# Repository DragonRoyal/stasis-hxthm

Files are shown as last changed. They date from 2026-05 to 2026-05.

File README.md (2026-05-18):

# 3D Cursor Robotic Arm

A robotic arm controlled by a **barcode-scanned spherical dome** (“3D cursor”). By scanning different barcodes inside the dome with a barcode scanner, the arm moves to different points / presets. That same ability to control a robotic arm in a enclosed 3d space can be used in other applications such as a 3D mouse for cad, or even helping older people with wrist shakiness to autonomously pick and control objects

## Demo
- Video/demo: https://www.youtube.com/watch?v=vmy95ypN5ZI

## What this is
- **3D‑printed structure** (links, brackets, mounts)
- **SG90 micro servo** for a light-duty joint / end-effector motion
- **Larger servo** (MG996R-class) for higher-torque joint motion
- **28BYJ-48 5V stepper motor** for the base axis / positioning
- **Arduino Nano** as the main controller

## Bill of Materials (BOM)

| Category | Item | Qty | Notes |
|---|---:|---:|---|
| 3D Printed | Arm links (upper/lower) | 1 set | Print in PLA/PETG |
| 3D Printed | Servo brackets / mounts | 1 set | For SG90 + MG996R |
| 3D Printed | Stepper mount | 1 | For 28BYJ-48 |
| 3D Printed | Base plate + lid | 1 set | Houses electronics |
| 3D Printed | End-effector / claw parts | 1 set | See CAD folder |
| 3D Printed | Cable guides / strain relief | as needed | Optional but helpful |
| Electronics | Arduino Nano | 1 | Main controller |
| Electronics | SG90 micro servo | 1 | Small joint / gripper |
| Electronics | MG996R servo (or similar) | 1 | Higher torque joint |
| Electronics | 28BYJ-48 5V stepper motor | 1 | Base axis |
| Electronics | Stepper driver board (ULN2003) | 1 | Common driver for 28BYJ-48 |
| Electronics | Power supply breakout boards | 1+ | As used in build |
| Electronics | 9V batteries | 1+ | As used in build |
| Electronics | Jumper wires | 1 set | Male/male + male/female |
| Electronics | Breadboard / perfboard | 0–1 | Optional |
| Hardware | M3 screws + nuts | assorted | Primary fasteners |
| Hardware | Heat-set inserts | optional | Recommended for durability |
| Hardware | Zip ties / Velcro | assorted | Cable management |
| Tools | 3D printer | 1 | — |
| Tools | Soldering iron + solder | 1 | — |
| Tools | Hex drivers / screwdrivers | 1 set | — |

## Pictures

Build photos (preview):

Arm build photo 1

Arm build photo 2

## CAD

CAD Photo

## Electronics

Wiring / electronics photo (preview):

Electronics photo

## Firmware / Control
Hand detection with opencv, it can detect joints and observe open/close positions
Firmware / control notes (preview):

Firmware photo 1

Firmware photo 2

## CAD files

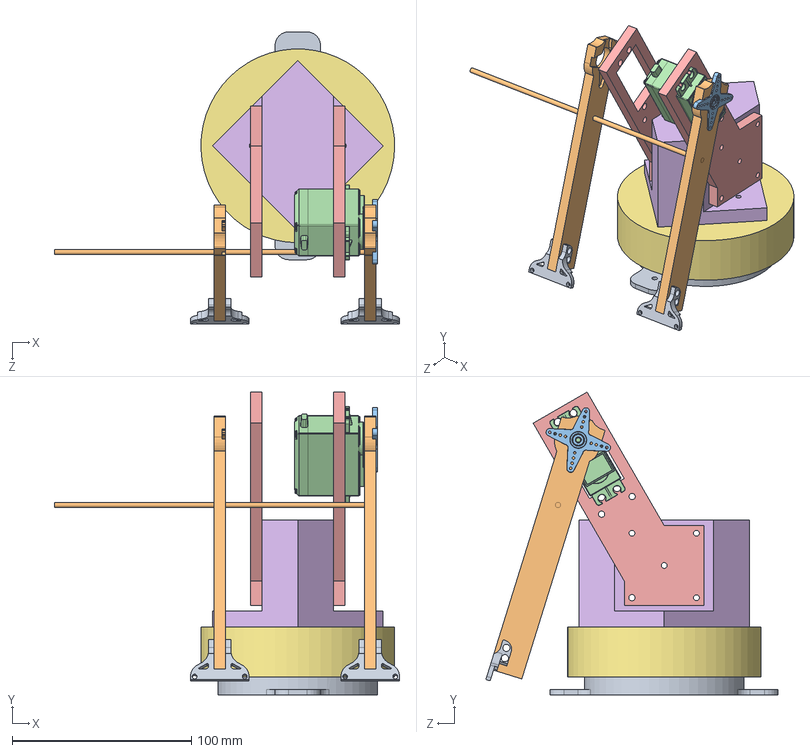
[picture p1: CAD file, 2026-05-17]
cad/Assembly.SLDASM
192.2 x 168.8 x 162.9 mm
Base
Stepper motor 28BYJ-48 5V
BaseLid
ArmGusset
LowerArm x 2
MG996R Motor
4-star horn
armLinkage x 2
adapter x 2

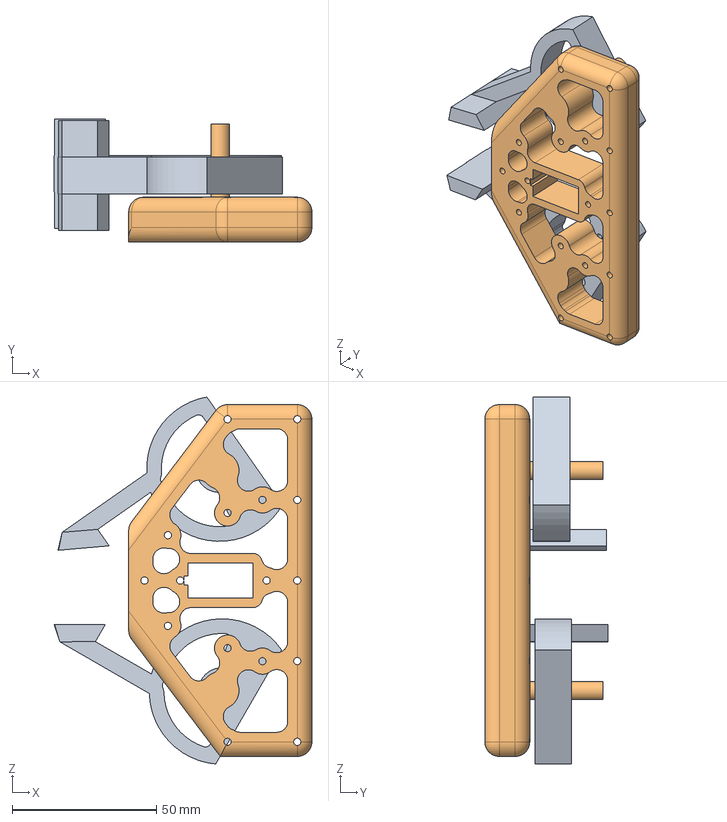
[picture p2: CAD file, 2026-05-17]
cad/STL/FullClaw.step
89.4 x 42.8 x 127.2 mm

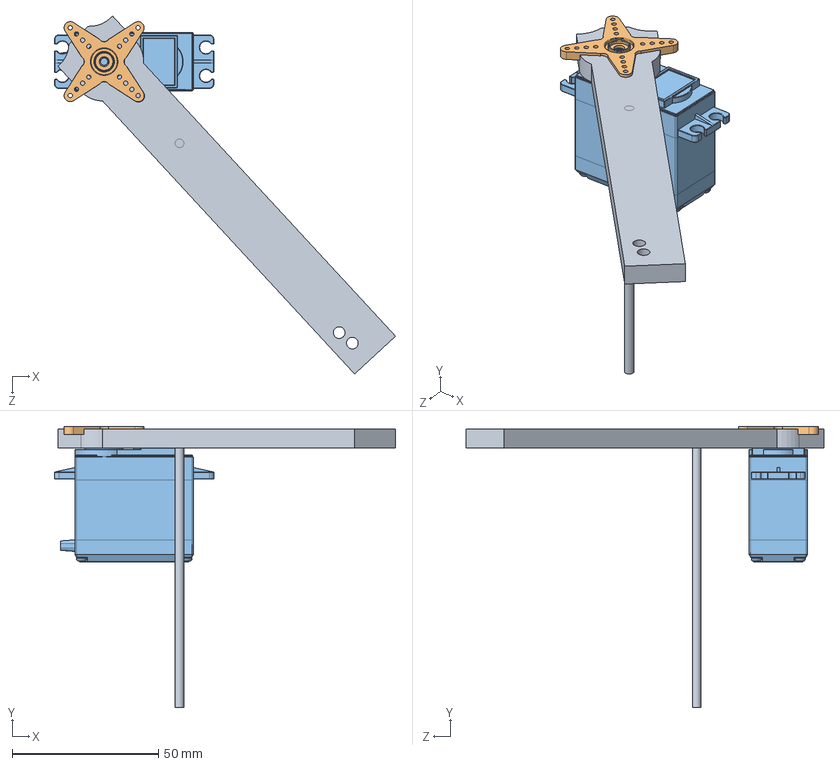
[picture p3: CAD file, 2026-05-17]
cad/pivot_assem.SLDASM
116.6 x 96.1 x 122.4 mm
MG996R Motor
4-star horn
armLinkage

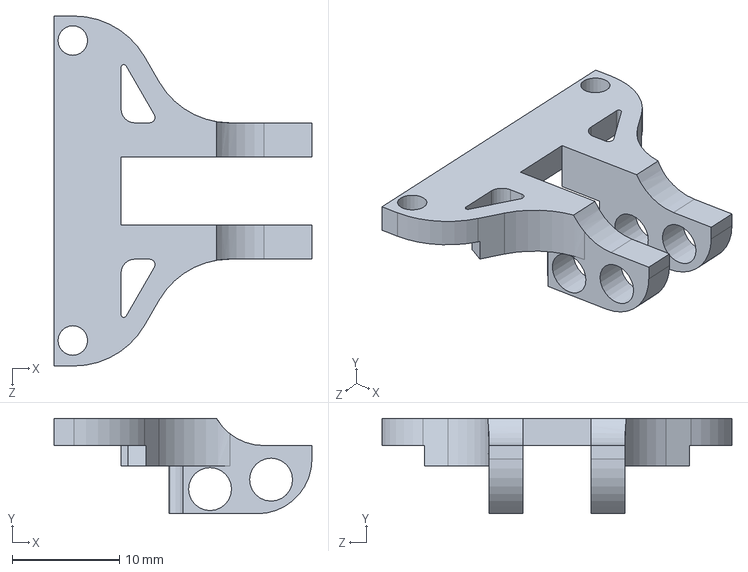
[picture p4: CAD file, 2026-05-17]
cad/STL/adapter.SLDPRT
24.0 x 8.89 x 32.6 mm

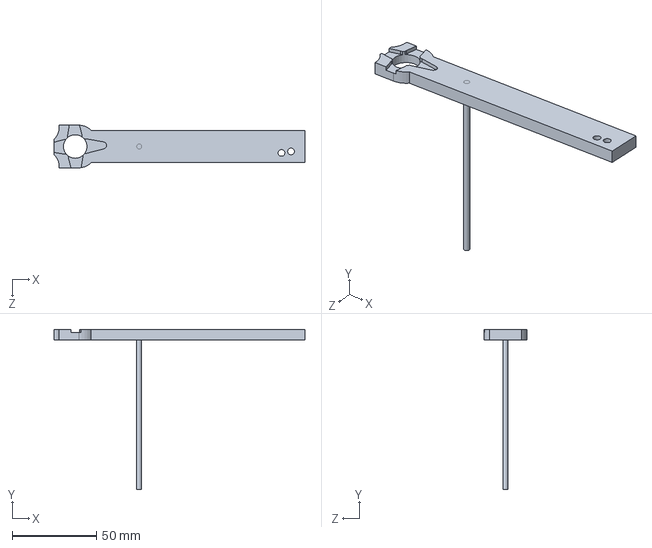
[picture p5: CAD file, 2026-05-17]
cad/armLinkage.SLDPRT
149.1 x 95.2 x 25.4 mm

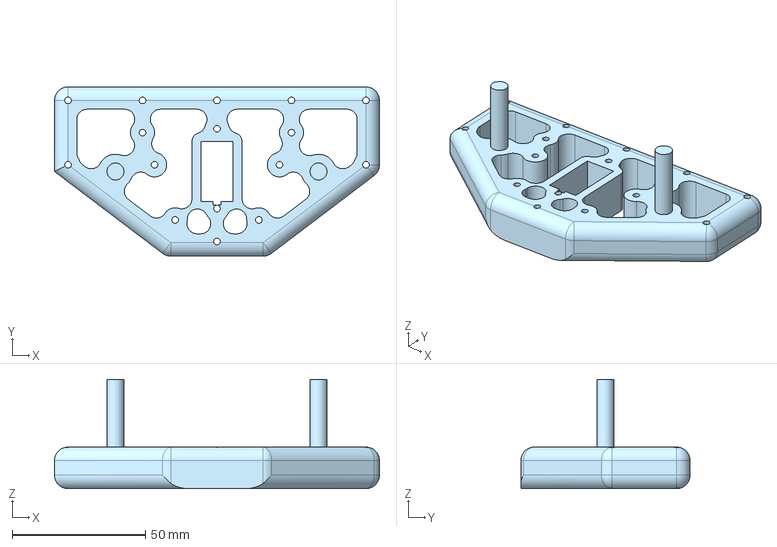
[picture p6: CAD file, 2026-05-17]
cad/STL/ClawBase.step
122.0 x 63.5 x 41.0 mm

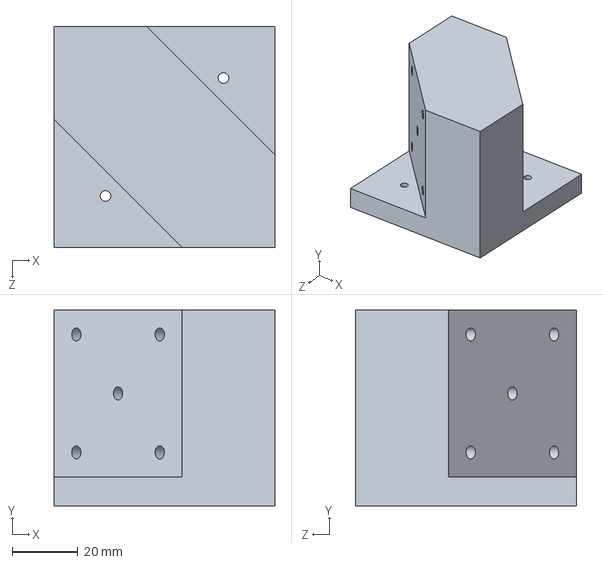
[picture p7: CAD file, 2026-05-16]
cad/ArmGusset.SLDPRT
67.3 x 59.7 x 67.3 mm

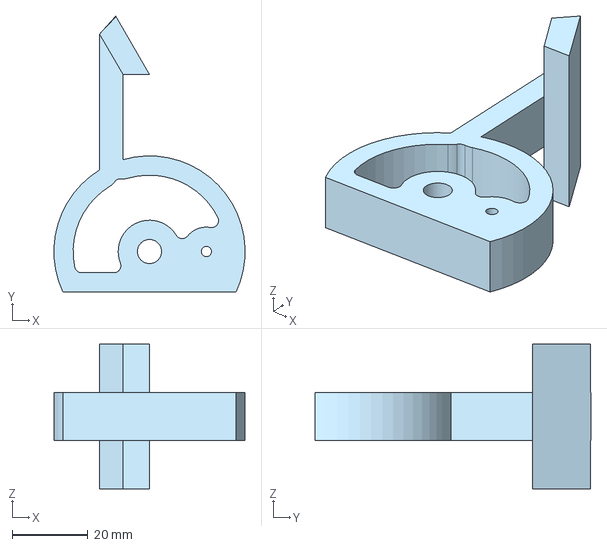
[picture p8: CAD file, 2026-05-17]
cad/STL/ClawClamp.step
50.3 x 72.7 x 38.1 mm

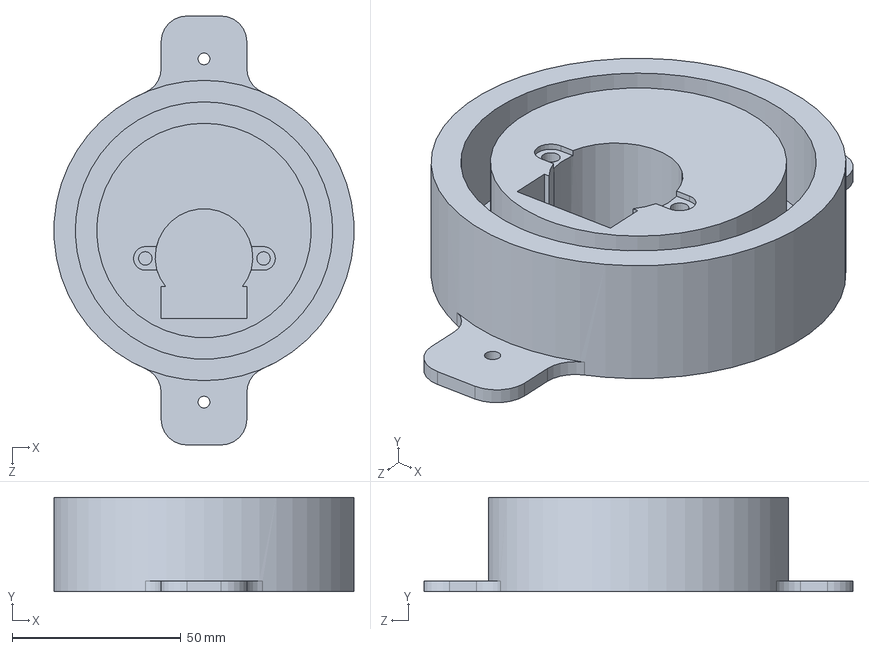
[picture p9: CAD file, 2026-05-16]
cad/Base.SLDPRT
88.7 x 27.9 x 127.0 mm

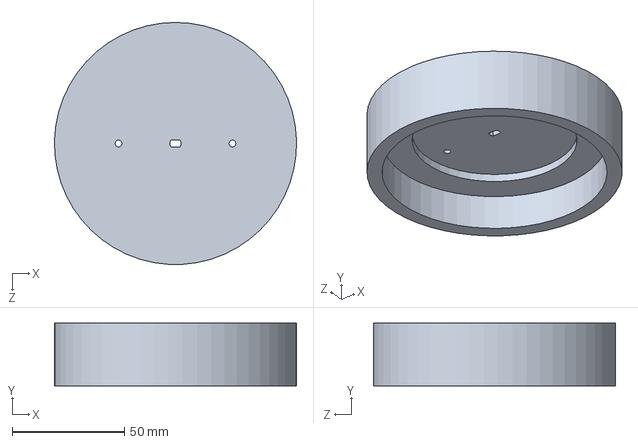
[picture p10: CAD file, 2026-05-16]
cad/BaseLid.SLDPRT
107.9 x 27.9 x 108.0 mm

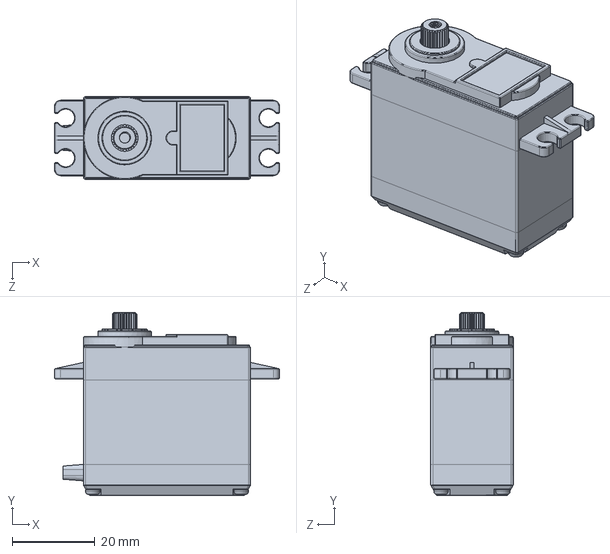
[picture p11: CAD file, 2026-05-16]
cad/MG996R Motor.SLDPRT
54.5 x 44.4 x 20.0 mm

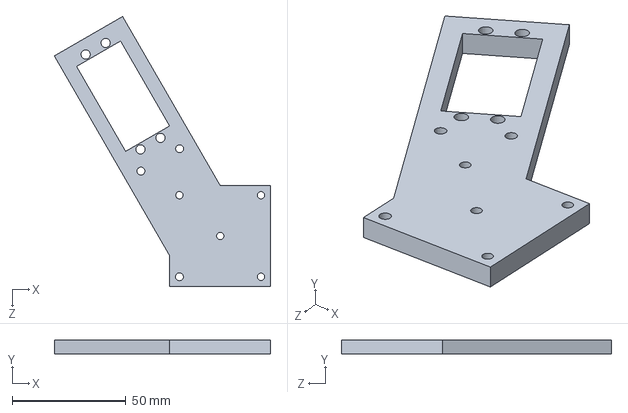
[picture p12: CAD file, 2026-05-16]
cad/LowerArm.SLDPRT
95.2 x 6.35 x 118.9 mm

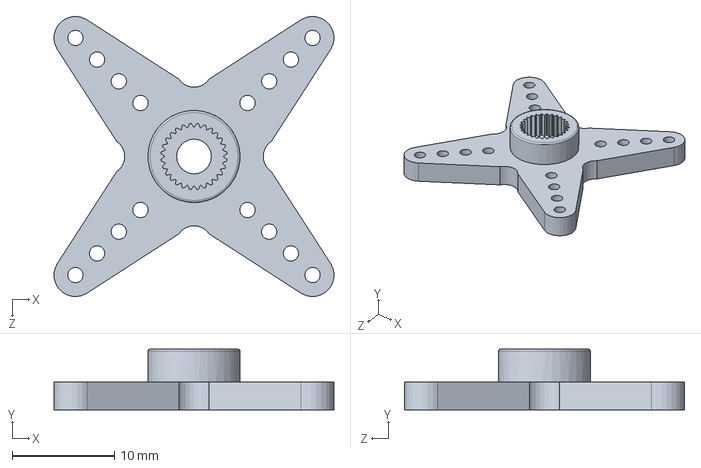
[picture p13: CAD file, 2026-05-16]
cad/4-star horn.SLDPRT
27.4 x 5.95 x 27.4 mm

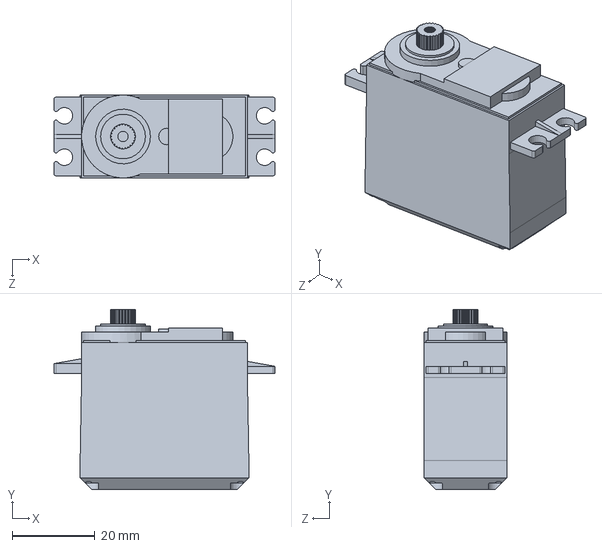
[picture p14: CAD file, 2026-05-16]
cad/MG996R_servo.SLDPRT
53.3 x 43.5 x 20.0 mm

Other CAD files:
cad/Stepper motor 28BYJ-48 5V.SLDPRT
cad/STL/ArmGusset.STL
cad/STL/Base.STL
cad/STL/ClawClamp.x_t
cad/STL/ClawHold.x_t
cad/STL/FullClaw.SLDASM
cad/STL/LowerArm.STL

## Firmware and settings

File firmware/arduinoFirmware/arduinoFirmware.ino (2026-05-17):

/*
    O              -> open claw
    C              -> close claw
    P <degA> <degB> -> base (A) to degA, pivot (B) to degB, absolute, 0-180
                       A is the base servo, B is the pivot stepper
*/
#include <AccelStepper.h>
#include <Servo.h>

// ===== PIN CONFIG =====
const uint8_t BASE_SERVO_PIN = 9;   // <-- change if your base servo is on a different pin

const uint8_t PIVOT_IN1 = 4;
const uint8_t PIVOT_IN2 = 5;
const uint8_t PIVOT_IN3 = 6;
const uint8_t PIVOT_IN4 = 7;

const uint8_t CLAW_SERVO_PIN = 3;

// ===== MOTION CONFIG =====
const long  STEPS_PER_REV     = 4096L;
const float STEPS_PER_DEGREE  = STEPS_PER_REV / 360.0f;

const float PIVOT_MAX_SPEED = 360.0;
const float PIVOT_ACCEL     = 120.0;

const int MAX_ANGLE = 180;

const int CLAW_OPEN_ANGLE   = 25;
const int CLAW_CLOSED_ANGLE = 85;

AccelStepper pivotStepper(AccelStepper::HALF4WIRE, PIVOT_IN1, PIVOT_IN3, PIVOT_IN2, PIVOT_IN4);
Servo baseServo;
Servo claw;

// ===== STATE =====
int  posA = 0;          // base angle (servo)
int  posB = 0;          // pivot angle (stepper)
bool clawOpen = false;
bool servosAttached = false;
char line[48];
uint8_t lineLength = 0;

// ===== HELPERS =====
long degToSteps(long degrees) {
  if (degrees >= 0) return (long)(degrees * STEPS_PER_DEGREE + 0.5f);
  return (long)(degrees * STEPS_PER_DEGREE - 0.5f);
}

int clampAngle(int deg) {
  if (deg < 0) return 0;
  if (deg > MAX_ANGLE) return MAX_ANGLE;
  return deg;
}

bool stepperRunning() {
  return pivotStepper.distanceToGo() != 0;
}

void detachServosForStepping() {
  if (servosAttached) {
    baseServo.detach();
    claw.detach();
    servosAttached = false;
  }
}

void reattachServos() {
  if (!servosAttached) {
    baseServo.attach(BASE_SERVO_PIN);
    claw.attach(CLAW_SERVO_PIN);
    baseServo.write(posA);
    claw.write(clawOpen ? CLAW_OPEN_ANGLE : CLAW_CLOSED_ANGLE);
    servosAttached = true;
    delay(50);  // let the servos settle before stepper run() resumes
  }
}

void moveBothTo(int targetA, int targetB) {
  targetA = clampAngle(targetA);
  targetB = clampAngle(targetB);

  // Detach servos before the pivot stepper starts moving, to avoid timer conflict
  detachServosForStepping();

  // Drive the base servo, then start the pivot stepper toward its target
  // (We re-attach the base briefly to issue the command, then detach again.)
  baseServo.attach(BASE_SERVO_PIN);
  baseServo.write(targetA);
  delay(50);
  baseServo.detach();

  pivotStepper.moveTo(degToSteps(targetB));

  posA = targetA;
  posB = targetB;

  Serial.print(F("OK P "));
  Serial.print(posA);
  Serial.print(F(" "));
  Serial.println(posB);
}

void setClaw(bool open) {
  if (open == clawOpen && servosAttached) {
    Serial.println(F("OK CLAW nochange"));
    return;
  }

  reattachServos();

  claw.write(open ? CLAW_OPEN_ANGLE : CLAW_CLOSED_ANGLE);
  clawOpen = open;

  Serial.print(F("OK CLAW "));
  Serial.println(open ? F("open") : F("closed"));
}

void handleLine(char *cmd) {
  while (*cmd == ' ' || *cmd == '\t') cmd++;
  if (*cmd == '\0') return;

  char first = cmd[0];

  if (first == 'O' || first == 'o') { setClaw(true);  return; }
  if (first == 'C' || first == 'c') { setClaw(false); return; }

  if (first == 'P' || first == 'p') {
    int degA = 0, degB = 0;
    if (sscanf(cmd, " %*c %d %d", &degA, &degB) == 2) {
      moveBothTo(degA, degB);
      return;
    }
    Serial.println(F("ERR format"));
    return;
  }

  Serial.print(F("ERR unknown: "));
  Serial.println(cmd);
}

void readSerialLine() {
  while (Serial.available() > 0) {
    char c = (char)Serial.read();
    if (c == '\r' || c == '\n') {
      if (lineLength > 0) {
        line[lineLength] = '\0';
        handleLine(line);
        lineLength = 0;
      }
      return;
    }
    if (c >= 32 && c <= 126 && lineLength < sizeof(line) - 1) {
      line[lineLength++] = c;
    }
  }
}

void setup() {
  Serial.begin(115200);
  while (!Serial) { ; }

  pivotStepper.setMaxSpeed(PIVOT_MAX_SPEED);
  pivotStepper.setAcceleration(PIVOT_ACCEL);

  baseServo.attach(BASE_SERVO_PIN);
  baseServo.write(0);
  claw.attach(CLAW_SERVO_PIN);
  claw.write(CLAW_CLOSED_ANGLE);
  servosAttached = true;

  Serial.println(F("READY"));
}

void loop() {
  readSerialLine();
  pivotStepper.run();

  // Once the pivot stepper stops, reattach the servos automatically
  static bool prevRunning = false;
  bool running = stepperRunning();
  if (prevRunning && !running) {
    reattachServos();
  }
  prevRunning = running;
}

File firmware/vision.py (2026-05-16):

import cv2
import mediapipe as mp
import serial
import time
import threading
import tkinter as tk
from PIL import Image, ImageTk

# ===== CONFIG =====
COOLDOWN_SECONDS = 0.3
SHOW_PREVIEW = True

SERIAL_PORT = "/dev/cu.usbserial-1440"
SERIAL_BAUD = 115200
ARDUINO_BOOT_DELAY = 2.0
# ==================

mp_hands = mp.solutions.hands
mp_draw = mp.solutions.drawing_utils


def is_hand_open(landmarks):
    finger_pairs = [(8, 6), (12, 10), (16, 14), (20, 18)]
    extended = sum(1 for tip, pip in finger_pairs if landmarks[tip].y < landmarks[pip].y)
    thumb_extended = abs(landmarks[4].x - landmarks[0].x) > abs(landmarks[2].x - landmarks[0].x)
    if thumb_extended:
        extended += 1
    return extended >= 4


def connect_arduino():
    try:
        ser = serial.Serial(SERIAL_PORT, SERIAL_BAUD, timeout=1)
        time.sleep(ARDUINO_BOOT_DELAY)
        while ser.in_waiting:
            print("Arduino:", ser.readline().decode(errors="ignore").strip())
        print(f"Connected to Arduino on {SERIAL_PORT}")
        return ser
    except serial.SerialException as e:
        print(f"WARNING: could not open {SERIAL_PORT} ({e}). Running without Arduino.")
        return None


serial_lock = threading.Lock()


def send_line(ser, line):
    if ser is None:
        return
    with serial_lock:
        try:
            ser.write((line + "\n").encode())
            reply = ser.readline().decode(errors="ignore").strip()
            if reply:
                print("Arduino:", reply)
        except serial.SerialException as e:
            print(f"Serial write failed: {e}")


def send_claw(ser, opening):
    send_line(ser, "O" if opening else "C")


def main():
    arduino = connect_arduino()
    cap = cv2.VideoCapture(0)
    if not cap.isOpened():
        print("Could not open webcam.")
        return

    hands = mp_hands.Hands(
        max_num_hands=1,
        min_detection_confidence=0.7,
        min_tracking_confidence=0.5,
    )

    # ----- Tkinter UI -----
    root = tk.Tk()
    root.title("Hand Detector + Barcode Input")

    video_label = tk.Label(root)
    video_label.pack(padx=8, pady=8)

    tk.Label(root, text="Scan or type barcode, then press Enter:").pack(pady=(4, 0))
    entry = tk.Entry(root, width=40)
    entry.pack(pady=4)
    entry.focus_set()
    status = tk.Label(root, text="", fg="gray")
    status.pack(pady=(0, 8))

    def submit(event=None):
        text = entry.get().strip()
        if not text:
            return
        send_line(arduino, text)
        status.config(text=f"Sent: {text}")
        entry.delete(0, tk.END)

    entry.bind("<Return>", submit)
    tk.Button(root, text="Send", command=submit).pack(pady=(0, 8))

    # ----- State for hand detection -----
    state = {"prev": None, "last_open": 0.0, "last_close": 0.0}

    def update_frame():
        ok, frame = cap.read()
        if not ok:
            root.after(15, update_frame)
            return

        frame = cv2.flip(frame, 1)
        rgb = cv2.cvtColor(frame, cv2.COLOR_BGR2RGB)
        results = hands.process(rgb)

        current_state = None
        if results.multi_hand_landmarks:
            hand_landmarks = results.multi_hand_landmarks[0]
            current_state = "open" if is_hand_open(hand_landmarks.landmark) else "closed"
            mp_draw.draw_landmarks(frame, hand_landmarks, mp_hands.HAND_CONNECTIONS)
            cv2.putText(
                frame, current_state.upper(), (10, 40),
                cv2.FONT_HERSHEY_SIMPLEX, 1.2,
                (0, 255, 0) if current_state == "open" else (0, 0, 255), 3,
            )

        # Independent cooldowns per direction so a fast O->C->O sequence isn't blocked
        now = time.time()
        if (current_state is not None and state["prev"] is not None
                and current_state != state["prev"]):
            if (state["prev"] == "closed" and current_state == "open"
                    and now - state["last_open"] > COOLDOWN_SECONDS):
                send_claw(arduino, True)
                print("Triggered: open")
                state["last_open"] = now
            elif (state["prev"] == "open" and current_state == "closed"
                    and now - state["last_close"] > COOLDOWN_SECONDS):
                send_claw(arduino, False)
                print("Triggered: close")
                state["last_close"] = now

        if current_state is not None:
            state["prev"] = current_state

        if SHOW_PREVIEW:
            display = cv2.cvtColor(frame, cv2.COLOR_BGR2RGB)
            img = Image.fromarray(display)
            imgtk = ImageTk.PhotoImage(image=img)
            video_label.imgtk = imgtk
            video_label.configure(image=imgtk)

        root.after(15, update_frame)

    def on_close():
        cap.release()
        hands.close()
        if arduino is not None:
            arduino.close()
        root.destroy()

    root.protocol("WM_DELETE_WINDOW", on_close)
    update_frame()
    root.mainloop()


if __name__ == "__main__":
    main()

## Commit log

2026-05-16 Add placeholder for cad/
2026-05-16 Changed it such that the arduino firmware should respond directly to the python vision system.
2026-05-16 cad files for base
    [ArmGusset.SLDPRT, Assembly.SLDASM, Base.SLDPRT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]
2026-05-16 Added the CAD for the claw & the holds on it
    [ClawClamp.x_t, ClawHold.x_t]
2026-05-16 arm changes servo
    [ArmGusset.SLDPRT, Assembly.SLDASM, Base.SLDPRT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]
2026-05-16 changed files
    [4-star horn.SLDPRT, Assembly.SLDASM, LowerArm.SLDPRT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]
2026-05-16 change files
    [Assembly.SLDASM, armLinkage.SLDPRT, pivot_assem.SLDASM]
2026-05-16 Added better vision & made the arduino have another servo rather than stepper
    [ClawBase.step, ClawClamp.step, FullClaw.step]
2026-05-16 add adapter for claw to pivot
    [Assembly.SLDASM, FullClaw.SLDASM, adapter.SLDPRT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]
2026-05-16 push skibidi
    [ArmGusset.STL, Base.STL, LowerArm.STL]
2026-05-17 fixed cad
    [Assembly.SLDASM, ClawBase.step, ClawClamp.step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]
2026-05-18 Update README with project description, demo link placeholder, BOM, and documentation sections
2026-05-18 README: embed photo previews and convert BOM to table
